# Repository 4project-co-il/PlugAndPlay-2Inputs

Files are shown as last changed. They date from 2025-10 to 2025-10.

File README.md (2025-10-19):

# PlugAndPlay-2Inputs
# PlugAndPlay: Input module with 2 screw terminals
This is the repository with the files for PlugAndPlay input module with 2 screw terminals

That module has 2 screw terminals, connected to the 2 interrupt lines of the PnP connector and configured to provide interrupt on any change of each input.

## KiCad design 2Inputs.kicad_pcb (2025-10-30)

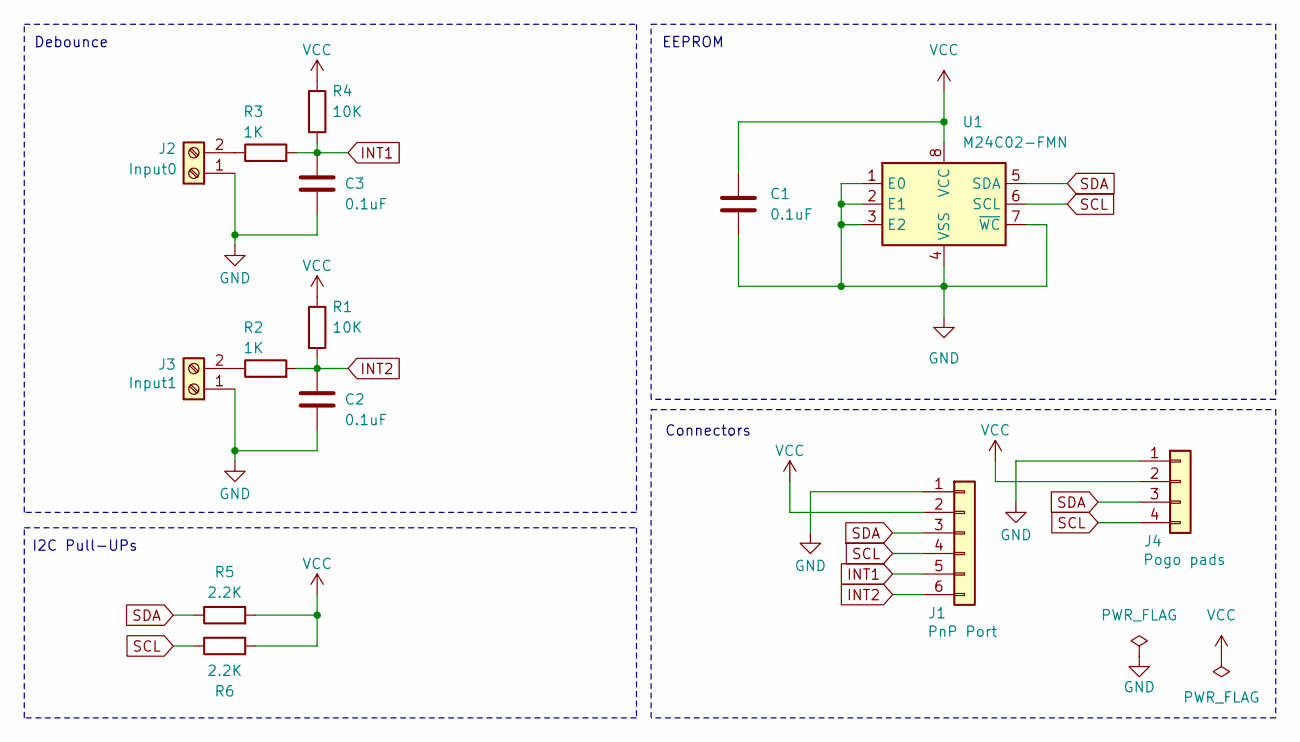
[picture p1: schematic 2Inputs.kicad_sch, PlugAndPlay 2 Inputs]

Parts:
C1, C2, C3: 0.1uF; C_0603_1608Metric; MPN C14663
J1: JST_SH_SM06B-SRSS-TB_1x06-1MP_P1.00mm_Horizontal; MPN C7430448
J2: Input0; TerminalBlock_4Ucon_1x02_P3.50mm_Horizontal
J3: Input1; TerminalBlock_4Ucon_1x02_P3.50mm_Horizontal
J4: Conn_01x04; PogoPinsPads_1x04_P2.5mm
R1, R4: 10K; R_0603_1608Metric; MPN C25804
R2, R3: 1K; R_0603_1608Metric; MPN C21190
R5, R6: 2.2K; R_0603_1608Metric; MPN C4190
U1: M24C02-FMN; SOIC-8_3.9x4.9mm_P1.27mm; MPN C114502

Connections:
GND: C1.2, C2.2, C3.2, J1.1, J2.1, J3.1, J4.1, U1.1 (E0), U1.2 (E1), U1.3 (E2), U1.4 (VSS), U1.7 (~WC)
INT1: C3.1, J1.5, R3.2, R4.2
INT2: C2.1, J1.6, R1.2, R2.2
unnamed: J2.2, R3.1
unnamed: J3.2, R2.1
SCL: J1.4, J4.4, R6.1, U1.6 (SCL)
SDA: J1.3, J4.3, R5.1, U1.5 (SDA)
VCC: C1.1, J1.2, J4.2, R1.1, R4.1, R5.2, R6.2, U1.8 (VCC)

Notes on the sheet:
EEPROM
Connectors
I2C Pull-UPs
Debounce

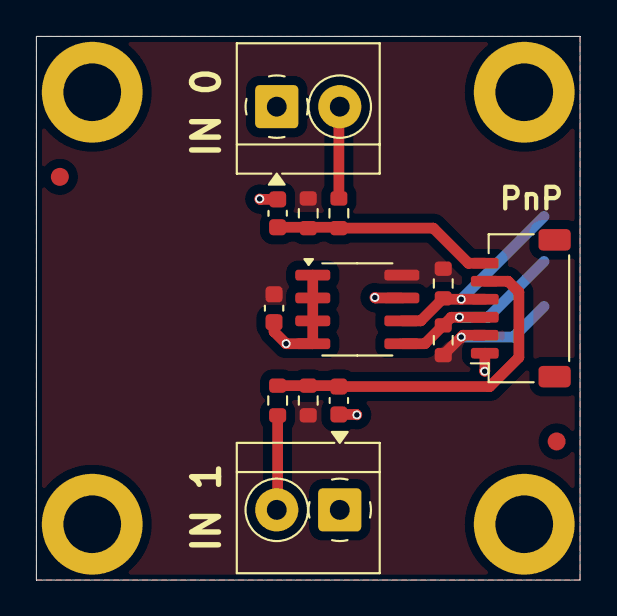
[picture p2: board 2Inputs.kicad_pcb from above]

Board: 2 copper layers, 30.2 x 30.2 mm, 14 parts (1 on the bottom side), 8 nets.

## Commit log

2025-10-23 Change screw terminals to 3.5mm version
    [2Inputs.kicad_pcb, 2Inputs.kicad_sch, panel.kicad_pcb]
2025-10-30 Hide bottom pads connector silk printouts
    [2Inputs.kicad_pcb]
2026-08-10 Change I2C pull-up resistors value to 4.7K
2026-10-06 BOM filename update
2026-10-14 Update BOM export parameters
